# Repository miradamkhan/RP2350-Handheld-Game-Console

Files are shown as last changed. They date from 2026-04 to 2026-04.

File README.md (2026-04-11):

# RP2350 Handheld Game Console

ECE 362 final project firmware and hardware files for a handheld game console built on the RP2350 Proton board.  
The current codebase includes a game-selection menu and three playable games: Tetris, 2048, and Space Invaders.

This README explains how to download the project, build it as-is, flash it, and test the hardware.

## Project Contents

- `src/`: Main firmware source (menu, games, drivers)
- `platformio.ini`: PlatformIO environment and build filter
- `Project_PCB/`: KiCad schematic and PCB files
- `Gameboy_Project_PCB.zip`: Packaged PCB design files

## Hardware Diagrams

### Schematic
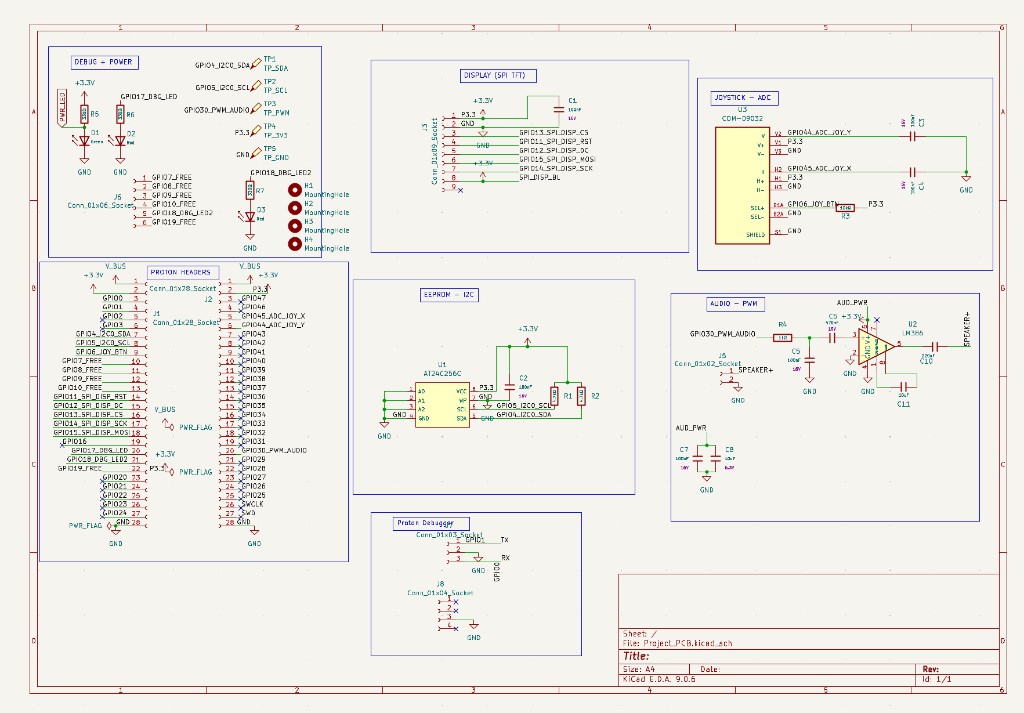
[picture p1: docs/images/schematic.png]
Schematic diagram


### PCB Layout
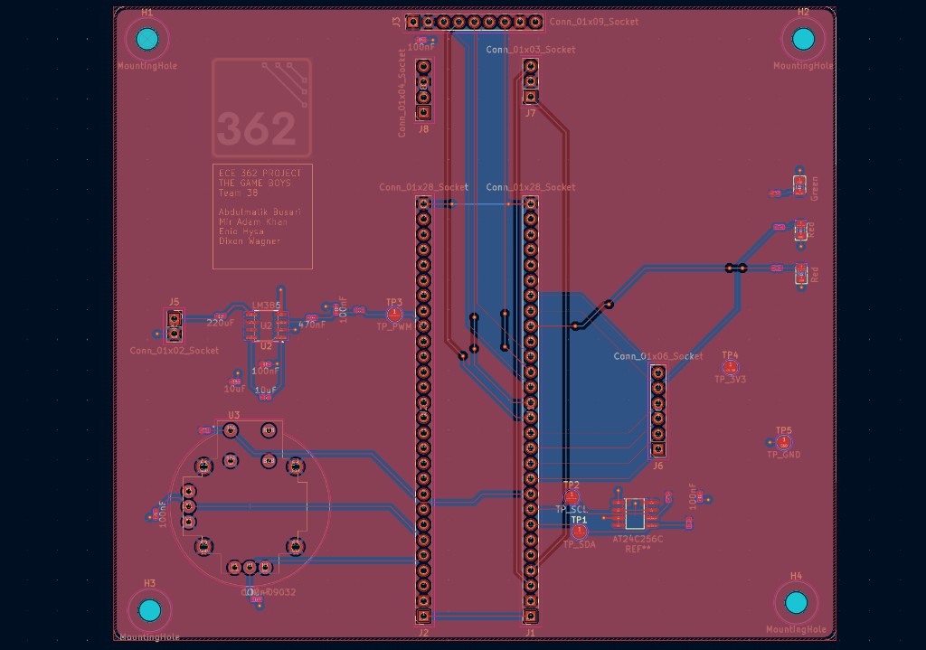
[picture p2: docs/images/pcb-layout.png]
PCB layout


## Requirements

- Windows, macOS, or Linux
- [VS Code](https://code.visualstudio.com/) with [PlatformIO IDE](https://platformio.org/install/ide?install=vscode), or PlatformIO Core CLI
- USB connection to the RP2350 board
- Debug/upload setup expected by this repo:
  - `picoprobe` upload/debug workflow (configured in `platformio.ini`)

## 1) Download the Project

### Option A: Clone with Git

```bash
git clone <repo-url>
cd RP2350-Handheld-Game-Console
```

### Option B: Download ZIP

1. Download the repository ZIP from GitHub.
2. Extract it.
3. Open the extracted folder in VS Code.

## 2) Build the Firmware

From the project root:

```bash
pio run -e proton
```

If the build succeeds, PlatformIO will generate firmware in `.pio/build/proton/`.

## 3) Flash to the Board

This project is configured for `picoprobe` upload:

```bash
pio run -e proton -t upload
```

If upload fails, verify:

- `picoprobe` is connected and detected
- The target board is powered
- Wiring and debug pins match your setup

## 4) Optional Serial Monitor

To open UART output:

```bash
pio device monitor -b 115200
```

## 5) Test the Project on Hardware

After flashing, the expected behavior is:

1. Boot splash appears.
2. Game menu appears with three options:
   - TETRIS
   - 2048
   - SPACE INVADERS
3. Joystick up/down changes the selected game.
4. Joystick button launches the selected game.
5. Exiting a game returns to the menu.
6. Leaderboard/high scores persist through EEPROM across resets.

### Input/Output Wiring Reference

- TFT SPI (ILI9341): `GPIO14` SCK, `GPIO15` MOSI, `GPIO13` CS, `GPIO12` DC, `GPIO11` RST
- EEPROM I2C: `GPIO4` SDA, `GPIO5` SCL
- Joystick ADC: `GPIO45` X, `GPIO44` Y, `GPIO6` button
- Extra buttons: `GPIO21` menu, `GPIO26` back
- Speaker PWM: `GPIO30`

## Notes on Scope

This repository is intentionally staying on the current feature set and game implementations.  
Future updates are expected to be small improvements (stability, polish, and maintainability), not major game rewrites.

## Team

- Enio Hysa
- Mir Adam Khan
- Abdulmalik Busari
- Dixon Wagner

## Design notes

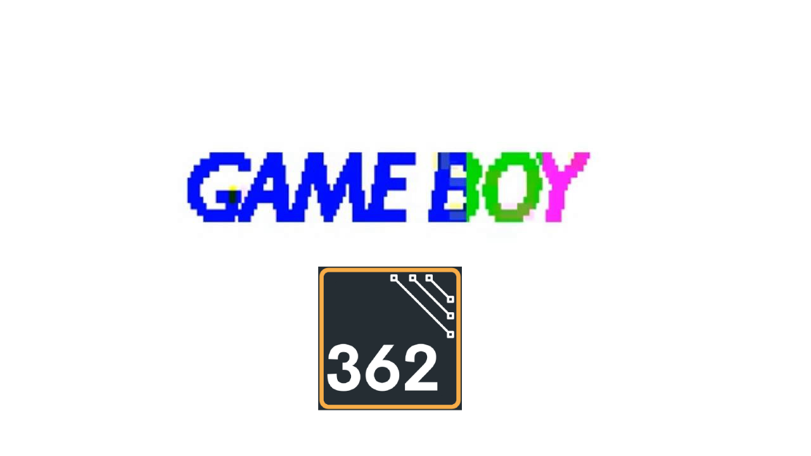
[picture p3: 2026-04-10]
src/gameboy362.png

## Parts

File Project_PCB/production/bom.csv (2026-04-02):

Designator | Footprint | Quantity | Value | LCSC Part #
C1, C2, C3, C4, C5, C7 | C_0402 | 6 | 100nF | C1525
C10 | C_0402 | 1 | 220uF | C1525
C11, C8 | C_0402 | 2 | 10uF | C15525
C6 | C_0402 | 1 | 470nF | C47339
D1 | D_0805 | 1 | Green | C2297
D2, D3 | D_0805 | 2 | Red | C84256
J1, J2 | PinSocket_1x28_P2.54mm_Vertical | 2 | Conn_01x28_Socket
J3 | PinSocket_1x09_P2.54mm_Vertical | 1 | Conn_01x09_Socket
J5 | PinSocket_1x02_P2.54mm_Vertical | 1 | Conn_01x02_Socket
J6 | PinSocket_1x06_P2.54mm_Vertical | 1 | Conn_01x06_Socket
J7 | PinSocket_1x03_P2.54mm_Vertical | 1 | Conn_01x03_Socket
J8 | PinSocket_1x04_P2.54mm_Vertical | 1 | Conn_01x04_Socket
R1, R2 | R_0402 | 2 | 4.7kΩ | C25900
R3 | R_0402 | 1 | 10kΩ | C25744
R4 | R_0402 | 1 | 1kΩ | C11702
R5, R6, R7 | R_0402 | 3 | 330Ω | C25104
TP1 | TestPoint_Pad_D2.0mm | 1 | TP_SDA
TP2 | TestPoint_Pad_D2.0mm | 1 | TP_SCL
TP3 | TestPoint_Pad_D2.0mm | 1 | TP_PWM
TP4 | TestPoint_Pad_D2.0mm | 1 | TP_3V3
TP5 | TestPoint_Pad_D2.0mm | 1 | TP_GND
U1 | SOIC-8_L4.9-W3.9-P1.27-LS6.0-BL | 1 | AT24C256C | C6482
U2 | SOIC-8_3.9x4.9mm_P1.27mm | 1 | LM386
U3 | XDCR_COM-09032 | 1 | COM-09032

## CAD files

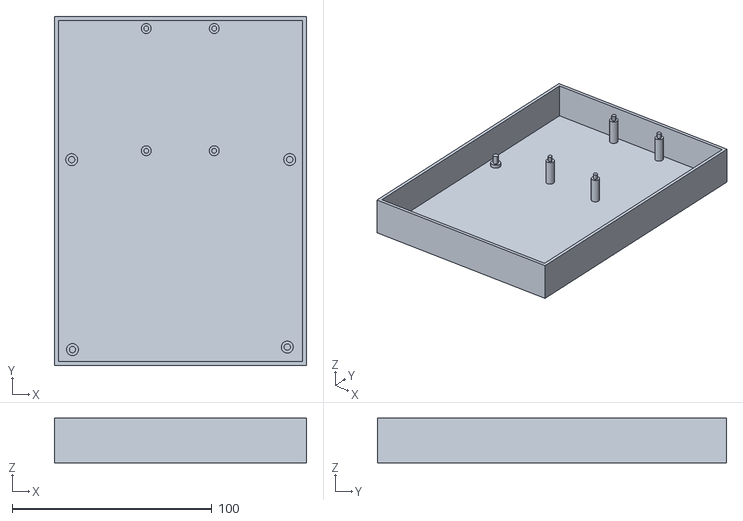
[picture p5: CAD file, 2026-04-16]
Part14.STL
126.1 x 174.6 x 22.3

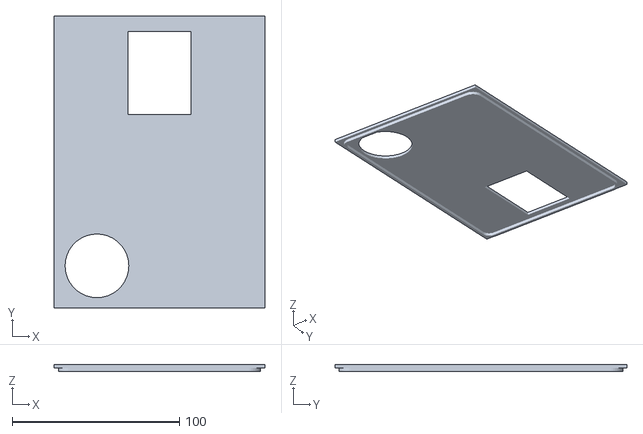
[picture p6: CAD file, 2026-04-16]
Top.STL
126.1 x 174.6 x 4.00

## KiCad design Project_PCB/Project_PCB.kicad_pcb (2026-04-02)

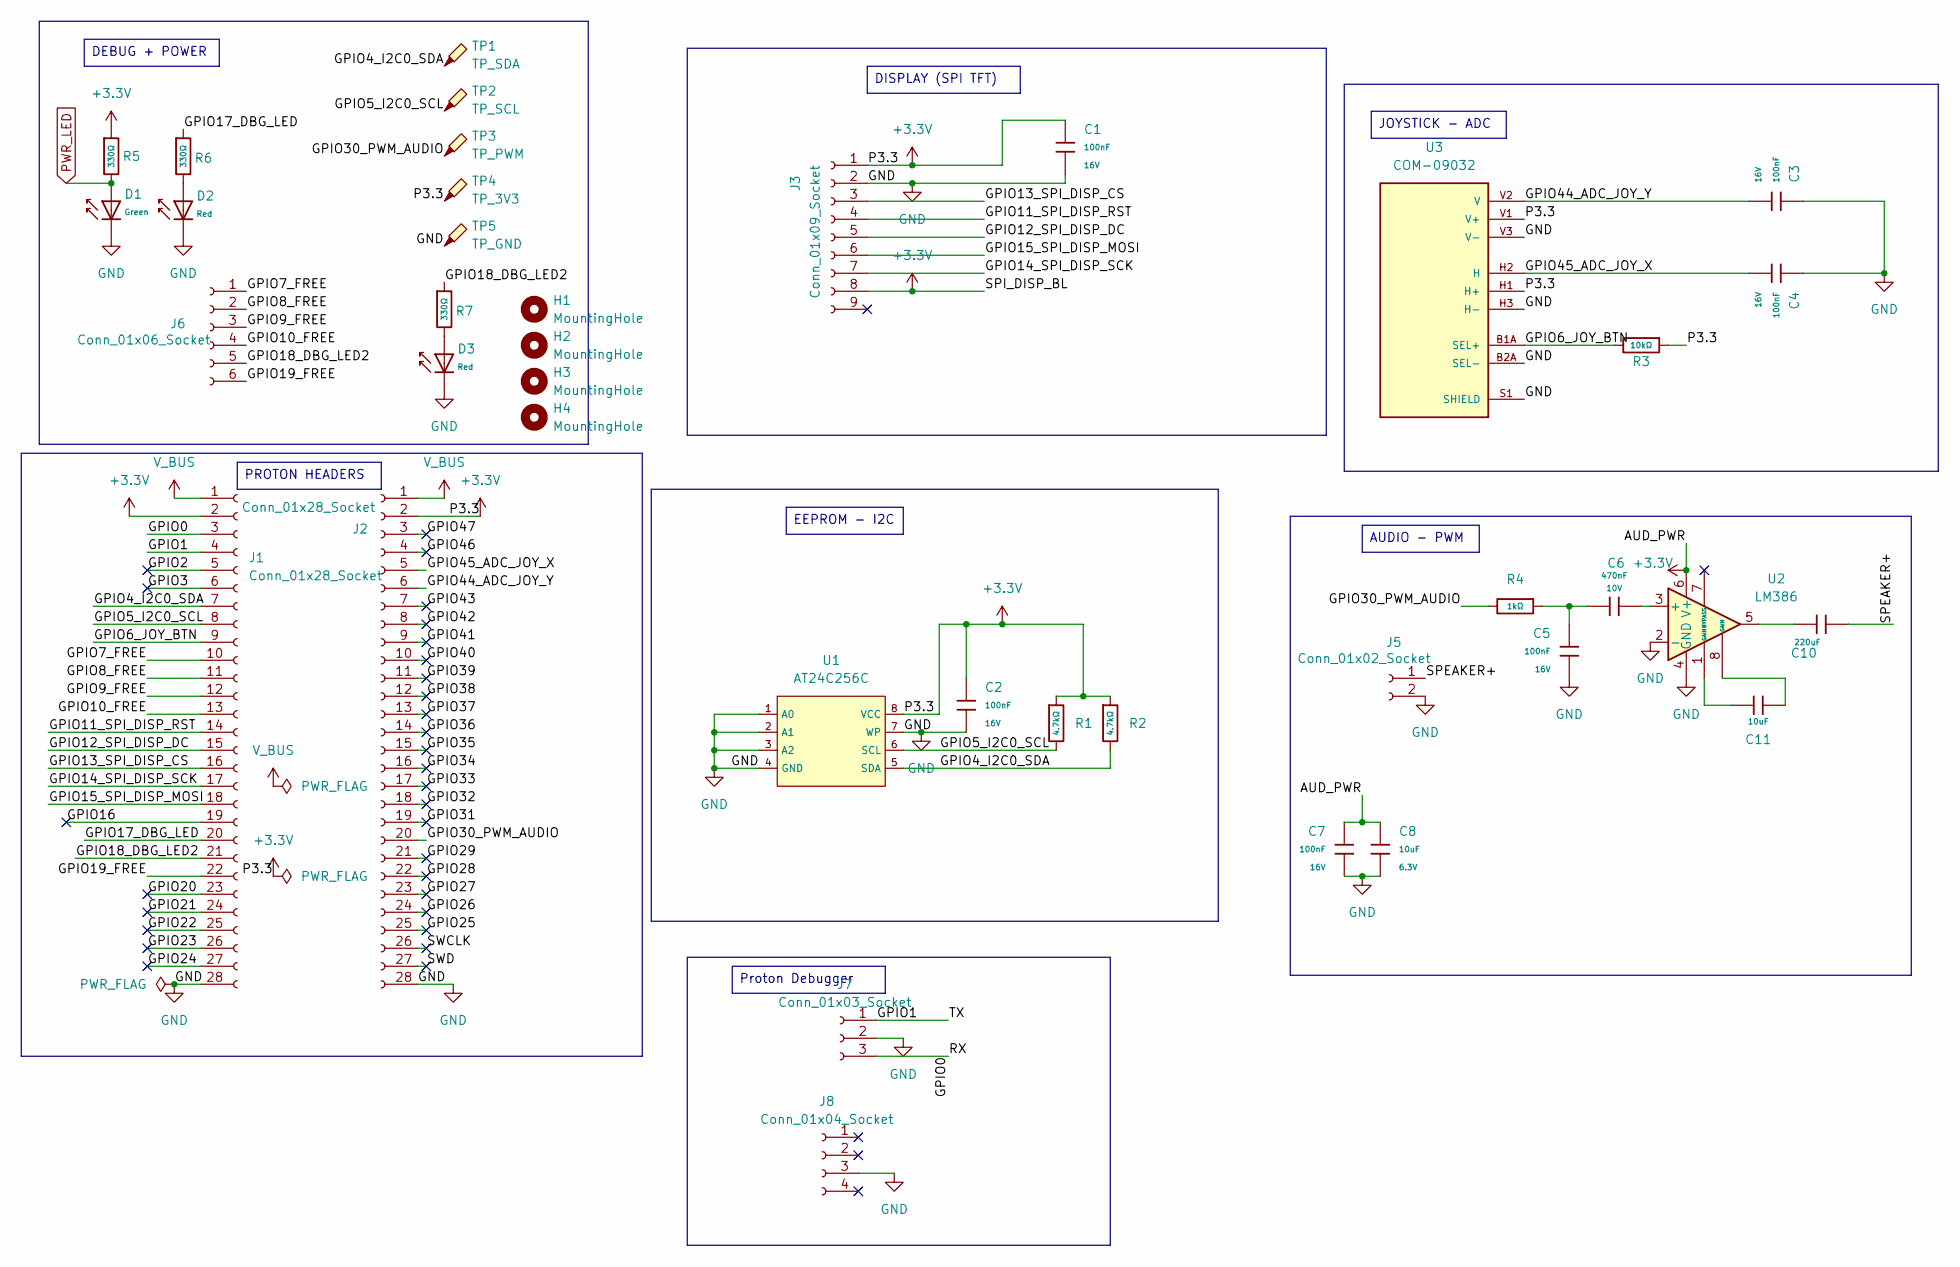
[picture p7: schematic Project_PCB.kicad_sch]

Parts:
C1, C2, C3, C4, C5, C7: 100nF; C_0402; Voltage Rated 16V; Tolerance ±10%; Part CL05B104KO5NNNC; LCSC C1525
C6: 470nF; C_0402; Voltage Rated 10V; Tolerance ±10%; Part CL05A474KP5NNNC; LCSC C47339
C8, C11: 10uF; C_0402; Voltage Rated 6.3V; Tolerance ±20%; Part CL05A106MQ5NUNC; LCSC C15525
C10: 220uF; C_0402; Voltage Rated 16V; Tolerance ±10%; Part CL05B104KO5NNNC; LCSC C1525
D1: Green; D_0805; Part KT-0805G; LCSC C2297
D2, D3: Red; D_0805; Forward Voltage (VF) 1.6V~2.6V; Part NCD0805R1; LCSC C84256
H1, H2, H3, H4: MountingHole; MountingHole_3.5mm
J1, J2: Conn_01x28_Socket; PinSocket_1x28_P2.54mm_Vertical
J3: Conn_01x09_Socket; PinSocket_1x09_P2.54mm_Vertical
J5: Conn_01x02_Socket; PinSocket_1x02_P2.54mm_Vertical
J6: Conn_01x06_Socket; PinSocket_1x06_P2.54mm_Vertical
J7: Conn_01x03_Socket; PinSocket_1x03_P2.54mm_Vertical
J8: Conn_01x04_Socket; PinSocket_1x04_P2.54mm_Vertical
R1, R2: 4.7kΩ; R_0402; Overload Voltage (Max) 50V; Tolerance ±1%; Part 0402WGF4701TCE; LCSC C25900
R3: 10kΩ; R_0402; Overload Voltage (Max) 50V; Tolerance ±1%; Part 0402WGF1002TCE; LCSC C25744
R4: 1kΩ; R_0402; Overload Voltage (Max) 50V; Tolerance ±1%; Part 0402WGF1001TCE; LCSC C11702
R5, R6, R7: 330Ω; R_0402; Overload Voltage (Max) 50V; Tolerance ±1%; Part 0402WGF3300TCE; LCSC C25104
TP1: TP_SDA; TestPoint_Pad_D2.0mm
TP2: TP_SCL; TestPoint_Pad_D2.0mm
TP3: TP_PWM; TestPoint_Pad_D2.0mm
TP4: TP_3V3; TestPoint_Pad_D2.0mm
TP5: TP_GND; TestPoint_Pad_D2.0mm
U1: AT24C256C; SOIC-8_L4.9-W3.9-P1.27-LS6.0-BL; Supply Voltage 1.7V~5.5V; Part AT24C256C-SSHL-T; LCSC C6482
U2: LM386; SOIC-8_3.9x4.9mm_P1.27mm
U3: COM-09032; XDCR_COM-09032; PARTREV N/A

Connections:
+3.3V: C1.1, C2.1, C7.1, C8.1, J1.2, J2.2, J3.1, J3.8, R1.1, R2.1, R3.1, R5.1, TP4.1, U1.8 (VCC), U2.6 (V+), U3.H1 (H+), U3.V1 (V+)
/GPIO0: J1.3, J7.3
/GPIO1: J1.4, J7.1
/GPIO2: J1.5
/GPIO3: J1.6
/GPIO4_I2C0_SDA: J1.7, R2.2, TP1.1, U1.5 (SDA)
/GPIO5_I2C0_SCL: J1.8, R1.2, TP2.1, U1.6 (SCL)
/GPIO6_JOY_BTN: J1.9, R3.2, U3.B1A (SEL+)
/GPIO7_FREE: J1.10, J6.1
/GPIO8_FREE: J1.11, J6.2
/GPIO9_FREE: J1.12, J6.3
/GPIO10_FREE: J1.13, J6.4
/GPIO11_SPI_DISP_RST: J1.14, J3.4
/GPIO12_SPI_DISP_DC: J1.15, J3.5
/GPIO13_SPI_DISP_CS: J1.16, J3.3
/GPIO14_SPI_DISP_SCK: J1.17, J3.7
/GPIO15_SPI_DISP_MOSI: J1.18, J3.6
/GPIO16: J1.19
/GPIO17_DBG_LED: J1.20, R6.1
/GPIO18_DBG_LED2: J1.21, J6.5, R7.1
/GPIO19_FREE: J1.22, J6.6
/GPIO20: J1.23
/GPIO21: J1.24
/GPIO22: J1.25
/GPIO23: J1.26
/GPIO24: J1.27
/GPIO25: J2.25
/GPIO26: J2.24
/GPIO27: J2.23
/GPIO28: J2.22
/GPIO29: J2.21
/GPIO30_PWM_AUDIO: J2.20, R4.2, TP3.1
/GPIO31: J2.19
/GPIO32: J2.18
/GPIO33: J2.17
/GPIO34: J2.16
/GPIO35: J2.15
/GPIO36: J2.14
/GPIO37: J2.13
/GPIO38: J2.12
/GPIO39: J2.11
/GPIO40: J2.10
/GPIO41: J2.9
/GPIO42: J2.8
/GPIO43: J2.7
/GPIO44_ADC_JOY_Y: C3.2, J2.6, U3.V2 (V)
/GPIO45_ADC_JOY_X: C4.2, J2.5, U3.H2 (H)
/GPIO46: J2.4
/GPIO47: J2.3
/SPEAKER+: C10.1, J5.1
/SWCLK: J2.26
/SWD: J2.27
GND: C1.2, C2.2, C3.1, C4.1, C5.2, C7.2, C8.2, D1.1, D2.1, D3.1, J1.28, J2.28, J3.2, J5.2, J7.2, J8.3, TP5.1, U1.1 (A0), U1.2 (A1), U1.3 (A2), U1.4 (GND), U1.7 (WP), U2.2 (-), U2.4 (GND), U3.B2A (SEL-), U3.H3 (H-), U3.S1 (SHIELD), U3.S2 (SHIELD), U3.S3 (SHIELD), U3.S4 (SHIELD), U3.V3 (V-)
unnamed: C5.1, C6.2, R4.1
unnamed: C10.2, U2.5
unnamed: C11.1, U2.1 (GAIN)
unnamed: C11.2, U2.8 (GAIN)
unnamed: D2.2, R6.2
unnamed: D3.2, R7.2
unnamed: C6.1, U2.3 (+)
PWR_LED: D1.2, R5.2
V_BUS: J1.1, J2.1

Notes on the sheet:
AUDIO - PWM
EEPROM - I2C
DEBUG + POWER
JOYSTICK - ADC
PROTON HEADERS
DISPLAY (SPI TFT)
Proton Debugger

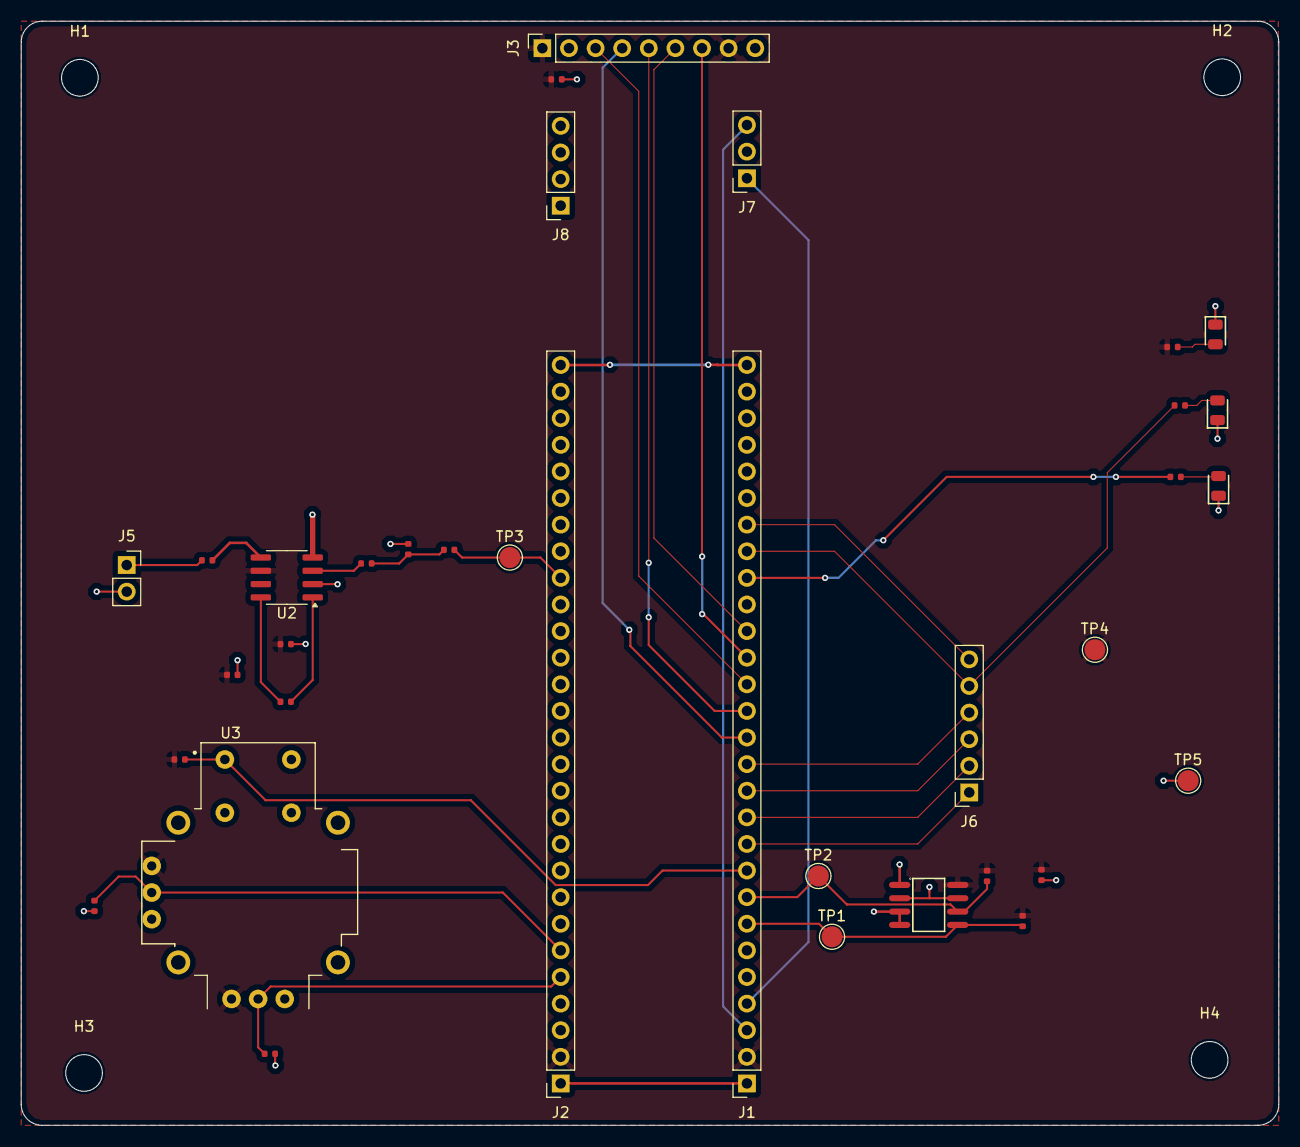
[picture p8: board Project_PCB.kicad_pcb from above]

Board: 2 copper layers, 120.1 x 105.4 mm, 39 parts (0 on the bottom side), 32 nets.

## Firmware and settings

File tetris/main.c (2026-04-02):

/*
 * main.c — Tetris for RP2350 Proton board.
 *
 * Ties together display, input, audio, EEPROM, and game logic.
 * Runs a ~30 FPS fixed-timestep loop.
 */

#include "pico/stdlib.h"

#include "pins.h"
#include "display.h"
#include "input.h"
#include "audio.h"
#include "eeprom.h"
#include "game.h"

#include <stdio.h>
#include <string.h>

/* ── Layout constants (pixels) ── */

#define BLOCK_SZ     12
#define BOARD_PX_X    8                           /* board left edge      */
#define BOARD_PX_Y   20                           /* board top edge       */
#define INFO_X      138                           /* info-panel left edge */
#define PREVIEW_SZ    8                           /* next-piece block px  */

/* ── Timing ── */

#define FRAME_MS        33   /* ~30 FPS */
#define DAS_DELAY_MS   170   /* auto-repeat initial delay */
#define DAS_REPEAT_MS   50   /* auto-repeat interval      */

/* ── Auto-repeat state ── */

static joy_dir_t s_prev_dir     = JOY_NONE;
static uint32_t  s_dir_start_ms = 0;
static uint32_t  s_dir_last_ms  = 0;

/* ── Previous game state for change detection ── */

static game_state_t s_prev_state = STATE_MENU;

/* ────────────────────────── helpers ───────────────────────────────── */

static void draw_number(uint16_t x, uint16_t y, uint32_t val,
                        uint16_t color, uint16_t bg, uint8_t scale)
{
    char buf[12];
    /* Convert to string manually to avoid pulling in snprintf. */
    int i = 0;
    if (val == 0) {
        buf[i++] = '0';
    } else {
        char tmp[11];
        int t = 0;
        while (val > 0) { tmp[t++] = '0' + (char)(val % 10); val /= 10; }
        while (t > 0) { buf[i++] = tmp[--t]; }
    }
    buf[i] = '\0';
    display_string(x, y, buf, color, bg, scale);
}

/* ────────────────────────── input mapping ─────────────────────────── */

static uint8_t map_input(const input_state_t *in, game_state_t state)
{
    uint8_t actions = ACTION_NONE;
    uint32_t now = to_ms_since_boot(get_absolute_time());
    joy_dir_t dir = in->direction;

    /* Left / right with DAS auto-repeat */
    if (dir == JOY_LEFT || dir == JOY_RIGHT) {
        bool fire = false;
        if (dir != s_prev_dir) {
            fire = true;
            s_dir_start_ms = now;
            s_dir_last_ms  = now;
        } else if ((now - s_dir_start_ms) >= DAS_DELAY_MS) {
            if ((now - s_dir_last_ms) >= DAS_REPEAT_MS) {
                fire = true;
                s_dir_last_ms = now;
            }
        }
        if (fire) {
            actions |= (dir == JOY_LEFT) ? ACTION_LEFT : ACTION_RIGHT;
        }
    }

    /* Soft drop — active every tick while held */
    if (dir == JOY_DOWN) {
        actions |= ACTION_DOWN;
    }

    /* Pause on joystick-up edge */
    if (dir == JOY_UP && s_prev_dir != JOY_UP) {
        actions |= ACTION_PAUSE;
    }

    s_prev_dir = dir;

    /* Button: context-dependent */
    if (in->button_pressed) {
        switch (state) {
        case STATE_MENU:      actions |= ACTION_SELECT; break;
        case STATE_PLAYING:   actions |= ACTION_ROTATE; break;
        case STATE_PAUSED:    actions |= ACTION_SELECT; break;
        case STATE_GAME_OVER: actions |= ACTION_SELECT; break;
        }
    }

    return actions;
}

/* ────────────────────────── rendering ─────────────────────────────── */

static void draw_board(const game_t *g)
{
    for (int r = 0; r < BOARD_H; r++) {
        for (int c = 0; c < BOARD_W; c++) {
            uint16_t color = COLOR_BLACK;
            uint8_t cell = g->board[r][c];
            if (cell != 0) {
                color = PIECE_COLORS[cell - 1];
            }

            /* Overlay active-piece cells */
            int pr = r - g->current.y;
            int pc = c - g->current.x;
            if (pr >= 0 && pr < TETRO_SIZE && pc >= 0 && pc < TETRO_SIZE) {
                if (TETROMINO_SHAPES[g->current.type]
                                    [g->current.rotation][pr][pc]) {
                    color = PIECE_COLORS[g->current.type];
                }
            }

            uint16_t px = BOARD_PX_X + (uint16_t)c * BLOCK_SZ;
            uint16_t py = BOARD_PX_Y + (uint16_t)r * BLOCK_SZ;
            display_fill_rect(px, py, BLOCK_SZ - 1, BLOCK_SZ - 1, color);
        }
    }
}

static void draw_board_border(void)
{
    uint16_t bw = (uint16_t)(BOARD_W * BLOCK_SZ);
    uint16_t bh = (uint16_t)(BOARD_H * BLOCK_SZ);
    uint16_t x0 = BOARD_PX_X - 1;
    uint16_t y0 = BOARD_PX_Y - 1;
    display_fill_rect(x0, y0, bw + 2, 1, COLOR_WHITE);         /* top    */
    display_fill_rect(x0, y0 + bh + 1, bw + 2, 1, COLOR_WHITE);/* bottom */
    display_fill_rect(x0, y0, 1, bh + 2, COLOR_WHITE);         /* left   */
    display_fill_rect(x0 + bw + 1, y0, 1, bh + 2, COLOR_WHITE);/* right  */
}

static void draw_info_panel(const game_t *g)
{
    uint16_t y = BOARD_PX_Y;
    uint16_t clr_w = 96;  /* width to clear for number fields */

    display_string(INFO_X, y, "SCORE", COLOR_GRAY, COLOR_BLACK, 1);
    y += 10;
    display_fill_rect(INFO_X, y, clr_w, 9, COLOR_BLACK);
    draw_number(INFO_X, y, g->score, COLOR_WHITE, COLOR_BLACK, 1);

    y += 18;
    display_string(INFO_X, y, "HIGH", COLOR_GRAY, COLOR_BLACK, 1);
    y += 10;
    display_fill_rect(INFO_X, y, clr_w, 9, COLOR_BLACK);
    draw_number(INFO_X, y, g->high_score, COLOR_YELLOW, COLOR_BLACK, 1);

    y += 18;
    display_string(INFO_X, y, "LEVEL", COLOR_GRAY, COLOR_BLACK, 1);
    y += 10;
    display_fill_rect(INFO_X, y, clr_w, 9, COLOR_BLACK);
    draw_number(INFO_X, y, (uint32_t)(g->level + 1), COLOR_GREEN, COLOR_BLACK, 1);

    y += 18;
    display_string(INFO_X, y, "LINES", COLOR_GRAY, COLOR_BLACK, 1);
    y += 10;
    display_fill_rect(INFO_X, y, clr_w, 9, COLOR_BLACK);
    draw_number(INFO_X, y, (uint32_t)g->lines_cleared, COLOR_CYAN, COLOR_BLACK, 1);

    /* Next piece preview */
    y += 20;
    display_string(INFO_X, y, "NEXT", COLOR_GRAY, COLOR_BLACK, 1);
    y += 10;
    uint16_t px0 = INFO_X;
    /* Clear preview area */
    display_fill_rect(px0, y, TETRO_SIZE * PREVIEW_SZ,
                      TETRO_SIZE * PREVIEW_SZ, COLOR_BLACK);
    for (int r = 0; r < TETRO_SIZE; r++) {
        for (int c = 0; c < TETRO_SIZE; c++) {
            if (TETROMINO_SHAPES[g->next.type][0][r][c]) {
                display_fill_rect(px0 + (uint16_t)c * PREVIEW_SZ,
                                  y   + (uint16_t)r * PREVIEW_SZ,
                                  PREVIEW_SZ - 1, PREVIEW_SZ - 1,
                                  PIECE_COLORS[g->next.type]);
            }
        }
    }
}

static void draw_menu(const game_t *g)
{
    display_fill(COLOR_BLACK);
    display_string(66, 60, "TETRIS", COLOR_CYAN, COLOR_BLACK, 3);
    display_string(30, 130, "Press Button", COLOR_WHITE, COLOR_BLACK, 2);
    display_string(48, 158, "to Start!", COLOR_WHITE, COLOR_BLACK, 2);

    display_string(INFO_X - 100, 230, "HIGH", COLOR_GRAY, COLOR_BLACK, 1);
    draw_number(INFO_X - 100, 242, g->high_score, COLOR_YELLOW, COLOR_BLACK, 2);
}

static void draw_playing_full(const game_t *g)
{
    display_fill(COLOR_BLACK);
    draw_board_border();
    draw_board(g);
    draw_info_panel(g);
}

static void draw_paused(void)
{
    display_fill_rect(30, 120, 180, 60, COLOR_BLACK);
    display_fill_rect(29, 119, 182, 62, COLOR_WHITE);
    display_fill_rect(30, 120, 180, 60, COLOR_BLACK);
    display_string(54, 140, "PAUSED", COLOR_WHITE, COLOR_BLACK, 3);
}

static void draw_game_over(const game_t *g)
{
    display_fill(COLOR_BLACK);
    display_string(15, 50, "GAME OVER", COLOR_RED, COLOR_BLACK, 3);

    display_string(24, 130, "SCORE", COLOR_GRAY, COLOR_BLACK, 2);
    draw_number(24, 158, g->score, COLOR_WHITE, COLOR_BLACK, 2);

    display_string(24, 200, "HIGH", COLOR_GRAY, COLOR_BLACK, 2);
    draw_number(24, 228, g->high_score, COLOR_YELLOW, COLOR_BLACK, 2);

    display_string(18, 290, "Press Button", COLOR_GRAY, COLOR_BLACK, 1);
}

/* ────────────────────────── audio events ──────────────────────────── */

static void handle_audio(const game_t *g)
{
    if (g->state_changed && g->state == STATE_GAME_OVER) {
        audio_play_sfx(SFX_GAME_OVER);
        return;
    }
    if (g->state_changed && g->state == STATE_PLAYING) {
        audio_play_sfx(SFX_MENU_SELECT);
        return;
    }
    if (g->lines_cleared_now > 0) {
        audio_play_sfx(SFX_LINE_CLEAR);
        return;
    }
    if (g->piece_locked_now) {
        audio_play_sfx(SFX_LOCK);
        return;
    }
    if (g->rotated_now) {
        audio_play_sfx(SFX_ROTATE);
    }
}

/* ────────────────────────── main ──────────────────────────────────── */

int main(void)
{
    stdio_init_all();

    gpio_init(PIN_DEBUG_LED);
    gpio_set_dir(PIN_DEBUG_LED, GPIO_OUT);
    gpio_put(PIN_DEBUG_LED, 1);

    /* Initialise hardware drivers. */
    display_init();
    input_init();
    audio_init();
    eeprom_init();

    /*
     * Uncomment one or more of these to run hardware tests at boot:
     *   display_test();
     *   input_test();
     *   audio_test();
     *   eeprom_test();
     */

    /* Load high score from EEPROM. */
    uint32_t high = eeprom_read_high_score();

    /* Initialise game state. */
    game_t g;
    game_init(&g, high);

    /* Draw initial menu. */
    draw_menu(&g);
    s_prev_state = STATE_MENU;

    /* ── Main loop ── */
    while (true) {
        uint32_t frame_start = to_ms_since_boot(get_absolute_time());

        /* 1. Read input */
        input_state_t in = input_read();
        uint8_t actions = map_input(&in, g.state);

        /* 2. Advance game logic */
        game_state_t cur = game_tick(&g, actions);

        /* 3. Render based on state transitions and dirty flags */
        if (g.state_changed) {
            switch (cur) {
            case STATE_MENU:      draw_menu(&g);           break;
            case STATE_PLAYING:   draw_playing_full(&g);   break;
            case STATE_PAUSED:    draw_paused();           break;
            case STATE_GAME_OVER:
                eeprom_write_high_score(g.score);
                draw_game_over(&g);
                break;
            }
        } else if (cur == STATE_PLAYING) {
            if (g.board_dirty)  draw_board(&g);
            if (g.score_dirty)  draw_info_panel(&g);
        }

        /* Clear dirty flags after rendering. */
        g.board_dirty = false;
        g.score_dirty = false;

        /* 4. Audio */
        handle_audio(&g);
        audio_update();

        /* 5. Frame-rate limiter */
        uint32_t elapsed = to_ms_since_boot(get_absolute_time()) - frame_start;
        if (elapsed < FRAME_MS) {
            sleep_ms(FRAME_MS - elapsed);
        }

        s_prev_state = cur;
    }

    return 0;  /* never reached */
}

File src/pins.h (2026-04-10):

/*
 * pins.h — Single source of truth for all GPIO/peripheral pin assignments.
 *
 * Target : RP2350 Proton board
 *
 * Display (only): MSP2202 — ILI9341, 4-wire SPI, 240×320 (see LCD wiki SKU).
 * https://www.lcdwiki.com/2.2inch_SPI_Module_ILI9341_SKU:MSP2202
 *
 * Per MSP2202 user manual (SPI section): D/C (RS) low = command, high = data;
 * SPI0-style timing CPOL=0, CPHA=0. (Do not invert D/C unless hardware inverts it.)
 *
 * EEPROM : 24AA32AF via I2C
 * Input  : Adafruit analog joystick #512 (2x ADC + 1 GPIO)
 * Audio  : PWM speaker output
 *
 * Pin choices avoid conflicts between SPI0, I2C0, ADC, and PWM.
 * All pins are validated against the RP2350 pin-mux table.
 */

#ifndef PINS_H
#define PINS_H

/* ── SPI1: ILI9341 TFT Display ── */
#define PIN_SPI_SCK     14  /* GP14 — SPI1 SCK */
#define PIN_SPI_MOSI    15  /* GP15 — SPI1 TX  */
#define PIN_TFT_CS      13  /* GP13 — manual CS */
#define PIN_TFT_DC      12  /* GP12 — data/cmd  */
#define PIN_TFT_RST     11  /* GP11 — reset     */
/* Set to the GPIO wired to TFT backlight (LED/BL/BLK). Use -1 if tied to 3V3. */
#define PIN_TFT_BL      -1

#define SPI_PORT        spi1
/* If the panel glitches, try 4_000_000 or 1_000_000. */
#define SPI_BAUD_HZ     4000000
/* Bring-up fallback: 1 = software SPI bit-bang on SCK/MOSI pins. */
#define TFT_USE_SOFT_SPI 0

/*
 * SPI mode: MSP2202 manual — SPI0, CPOL=0, CPHA=0 (RP2040/2350 “mode 0”).
 */
#ifndef TFT_SPI_MODE
#define TFT_SPI_MODE    0
#endif

/*
 * D/C invert: 0 = MSP2202 manual / ILI9341 (low=command, high=data).
 * Set to 1 only if your PCB inverts the D/C line to the panel.
 */
#ifndef TFT_DC_INVERT
#define TFT_DC_INVERT   0
#endif

/* ── I2C0: 24AA32AF EEPROM ── */
#define PIN_I2C_SDA     4   /* GP4 — I2C0 SDA */
#define PIN_I2C_SCL     5   /* GP5 — I2C0 SCL */

#define I2C_PORT        i2c0
#define I2C_BAUD_HZ     400000    /* 400 kHz fast-mode */

/* ── ADC: Adafruit Joystick #512 ── */
#define PIN_JOY_X       45  /* GP45 — ADC5 */
#define PIN_JOY_Y       44  /* GP44 — ADC4 */
#define ADC_CHAN_X       5
#define ADC_CHAN_Y       4

/* ── GPIO: Joystick select button (active-low, internal pull-up) ── */
#define PIN_JOY_BTN     6   /* GP6 */
/* Dedicated game-control buttons (active-low, internal pull-up). */
#define PIN_BTN_MENU    21  /* GP21: pause/menu */
#define PIN_BTN_BACK    26  /* GP26: back/exit  */

/* ── PWM: Speaker ── */
#define PIN_SPEAKER     30  /* GP30 */

/* ── Debug ── */
#define PIN_DEBUG_LED   17  /* GP17 */

/* ── Display geometry (ILI9341) ── */
#define TFT_WIDTH       240
#define TFT_HEIGHT      320

#endif /* PINS_H */

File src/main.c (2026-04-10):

/*
 * main.c — RP2350 Handheld Game Console main menu.
 *
 * Displays a game selection menu on boot. The user scrolls with the
 * joystick (up/down) and presses the button to launch a game.
 * When the game returns, the menu is re-displayed.
 */

#include "pico/stdlib.h"

#include "pins.h"
#include "display.h"
#include "input.h"
#include "audio.h"
#include "eeprom.h"
#include "tetris_render.h"
#include "game2048.h"
#include "invaders.h"

#include <stdio.h>

#define NUM_GAMES      3
#define MENU_FRAME_MS 50

static const char *game_names[NUM_GAMES] = {
    "TETRIS",
    "2048",
    "SPACE INVADERS"
};

static void draw_number(uint16_t x, uint16_t y, uint32_t val,
                        uint16_t color, uint16_t bg, uint8_t scale)
{
    char buf[12];
    int i = 0;
    if (val == 0) {
        buf[i++] = '0';
    } else {
        char tmp[11];
        int t = 0;
        while (val > 0) { tmp[t++] = '0' + (char)(val % 10); val /= 10; }
        while (t > 0) { buf[i++] = tmp[--t]; }
    }
    buf[i] = '\0';
    display_string(x, y, buf, color, bg, scale);
}

static void show_boot_splash(void)
{
    display_fill(COLOR_WHITE);

    display_string(10, 26, "AbdulMalik Busari, Enio Hysa,", COLOR_BLACK, COLOR_WHITE, 1);
    display_string(12, 40, "Mir Adam Khan, Dixon Wagner", COLOR_BLACK, COLOR_WHITE, 1);

    /* Approximate the GAME BOY 362 startup card styling. */
    display_string(34, 88,  "GAME", COLOR_BLUE,    COLOR_WHITE, 4);
    display_string(130, 88, "BOY",  COLOR_GREEN,   COLOR_WHITE, 4);

    display_fill_rect(74, 168, 92, 100, COLOR_DARK_GRAY);
    display_fill_rect(72, 166, 96, 104, COLOR_ORANGE);
    display_fill_rect(76, 170, 88, 96, COLOR_DARK_GRAY);
    display_string(90, 208, "362", COLOR_WHITE, COLOR_DARK_GRAY, 3);

    sleep_ms(2200);
}

static void draw_menu(int selected)
{
    uint32_t hs_tetris   = eeprom_read_high_score(EEPROM_ADDR_TETRIS_HS);
    uint32_t hs_2048     = eeprom_read_high_score(EEPROM_ADDR_2048_HS);
    uint32_t hs_invaders = eeprom_read_high_score(EEPROM_ADDR_INVADERS_HS);

    display_fill(COLOR_BLACK);

    display_string(30, 30, "SELECT GAME", COLOR_CYAN, COLOR_BLACK, 2);
    display_fill_rect(20, 52, 200, 2, COLOR_CYAN);

    for (int i = 0; i < NUM_GAMES; i++) {
        uint16_t y = (uint16_t)(80 + i * 52);
        uint16_t box_x = 20;
        uint16_t box_w = 200;
        uint16_t box_h = 40;

        if (i == selected) {
            display_fill_rect(box_x, y, box_w, box_h, COLOR_CYAN);
            display_string(box_x + 10, y + 12, game_names[i],
                           COLOR_BLACK, COLOR_CYAN, 2);
            display_string(box_x - 14, y + 12, ">", COLOR_YELLOW, COLOR_BLACK, 2);
        } else {
            display_fill_rect(box_x, y, box_w, 2, COLOR_GRAY);
            display_fill_rect(box_x, y + box_h - 2, box_w, 2, COLOR_GRAY);
            display_fill_rect(box_x, y, 2, box_h, COLOR_GRAY);
            display_fill_rect(box_x + box_w - 2, y, 2, box_h, COLOR_GRAY);
            display_string(box_x + 10, y + 12, game_names[i],
                           COLOR_WHITE, COLOR_BLACK, 2);
        }
    }

    /* Leaderboard card */
    display_fill_rect(12, 232, 216, 70, COLOR_DARK_GRAY);
    display_fill_rect(14, 234, 212, 66, COLOR_BLACK);
    display_string(66, 238, "LEADERBOARD", COLOR_CYAN, COLOR_BLACK, 1);

    display_string(20, 252, "TETRIS", COLOR_GRAY, COLOR_BLACK, 1);
    draw_number(164, 252, hs_tetris, COLOR_WHITE, COLOR_BLACK, 1);

    display_string(20, 266, "2048", COLOR_GRAY, COLOR_BLACK, 1);
    draw_number(164, 266, hs_2048, COLOR_WHITE, COLOR_BLACK, 1);

    display_string(20, 280, "INVADERS", COLOR_GRAY, COLOR_BLACK, 1);
    draw_number(164, 280, hs_invaders, COLOR_WHITE, COLOR_BLACK, 1);

    display_string(16, 306, "UP/DOWN + BUTTON", COLOR_DARK_GRAY, COLOR_BLACK, 1);
}

int main(void)
{
    stdio_init_all();

    gpio_init(PIN_DEBUG_LED);
    gpio_set_dir(PIN_DEBUG_LED, GPIO_OUT);
    gpio_put(PIN_DEBUG_LED, 1);

    display_init();
    show_boot_splash();
    input_init();
    audio_init();
    eeprom_init();

    int selected = 0;
    joy_dir_t prev_dir = JOY_NONE;

    draw_menu(selected);

    while (true) {
        uint32_t frame_start = to_ms_since_boot(get_absolute_time());

        input_state_t in = input_read();
        audio_update();

        if (in.direction == JOY_UP && prev_dir != JOY_UP) {
            if (selected > 0) {
                selected--;
                audio_play_tone(280, 10); /* subtle menu hover */
                draw_menu(selected);
            }
        }
        if (in.direction == JOY_DOWN && prev_dir != JOY_DOWN) {
            if (selected < NUM_GAMES - 1) {
                selected++;
                audio_play_tone(280, 10); /* subtle menu hover */
                draw_menu(selected);
            }
        }
        prev_dir = in.direction;

        if (in.button_pressed) {
            audio_play_sfx(SFX_MENU_SELECT);
            sleep_ms(120);

            switch (selected) {
            case 0:
                tetris_run();
                break;
            case 1:
                game2048_run();
                break;
            case 2:
                invaders_run();
                break;
            }

            prev_dir = JOY_NONE;
            draw_menu(selected);
        }

        uint32_t elapsed = to_ms_since_boot(get_absolute_time()) - frame_start;
        if (elapsed < MENU_FRAME_MS) {
            sleep_ms(MENU_FRAME_MS - elapsed);
        }
    }

    return 0;
}

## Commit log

2026-03-31 Implement RP2350 Flappy Bird hardware integration.
    Add a complete Pico SDK-style modular codebase with ILI9341 TFT rendering, joystick ADC/button input, PWM audio effects, 24AA32AF EEPROM high-score storage, fixed-timestep game loop, and bring-up test routines.
    Made-with: Cursor
    [audio.c, display.c, eeprom.c]
2026-04-02 Update Flappy and Tetris to final hardware pin map.
    Remap SPI, I2C, ADC, GPIO button, PWM audio, and debug LED pins to the provided RP2350 wiring, and remove unused TFT backlight pin handling.
    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
2026-04-02 Added PCB files
    [Project_PCB.kicad_pcb, Project_PCB.kicad_sch, bom.csv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]
2026-04-10 fixed games and sounds
    [audio.c, input.c]
2026-04-16 Add files via upload
    Initial design of the Game Boy case
    [Part14.STL, Top.STL]
